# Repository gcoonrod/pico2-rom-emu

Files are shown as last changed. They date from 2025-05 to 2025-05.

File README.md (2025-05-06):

# Pico2-ROM-Emu

Pico2-ROM-Emu is a project designed to emulate 28 pin EEPROM (28C256 compatible) functionality using the Raspberry Pi Pico2 and a fast SRAM.

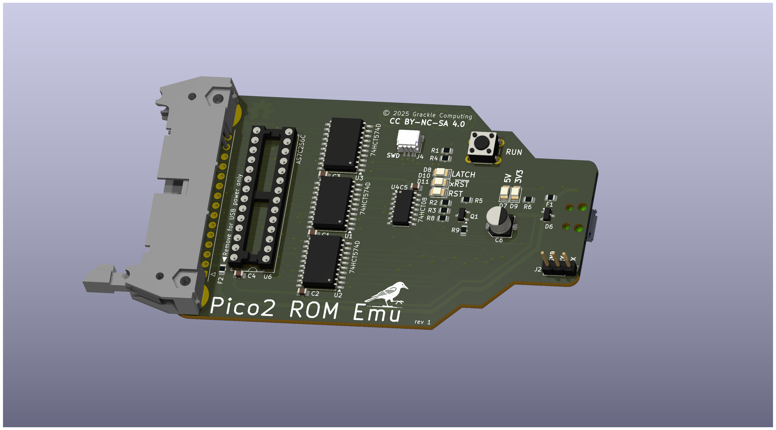
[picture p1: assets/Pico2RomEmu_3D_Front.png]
front render


## Theory of Operation
The theory of operation is relatively simple:

1. Assert active-low reset signal
2. Fill SRAM with ROM data using octal latches 
3. Hi-Z the latches and de-assert reset
4. SRAM is directly connected to DUT EEPROM socket via ribbon cable 

## Circuit Schematic
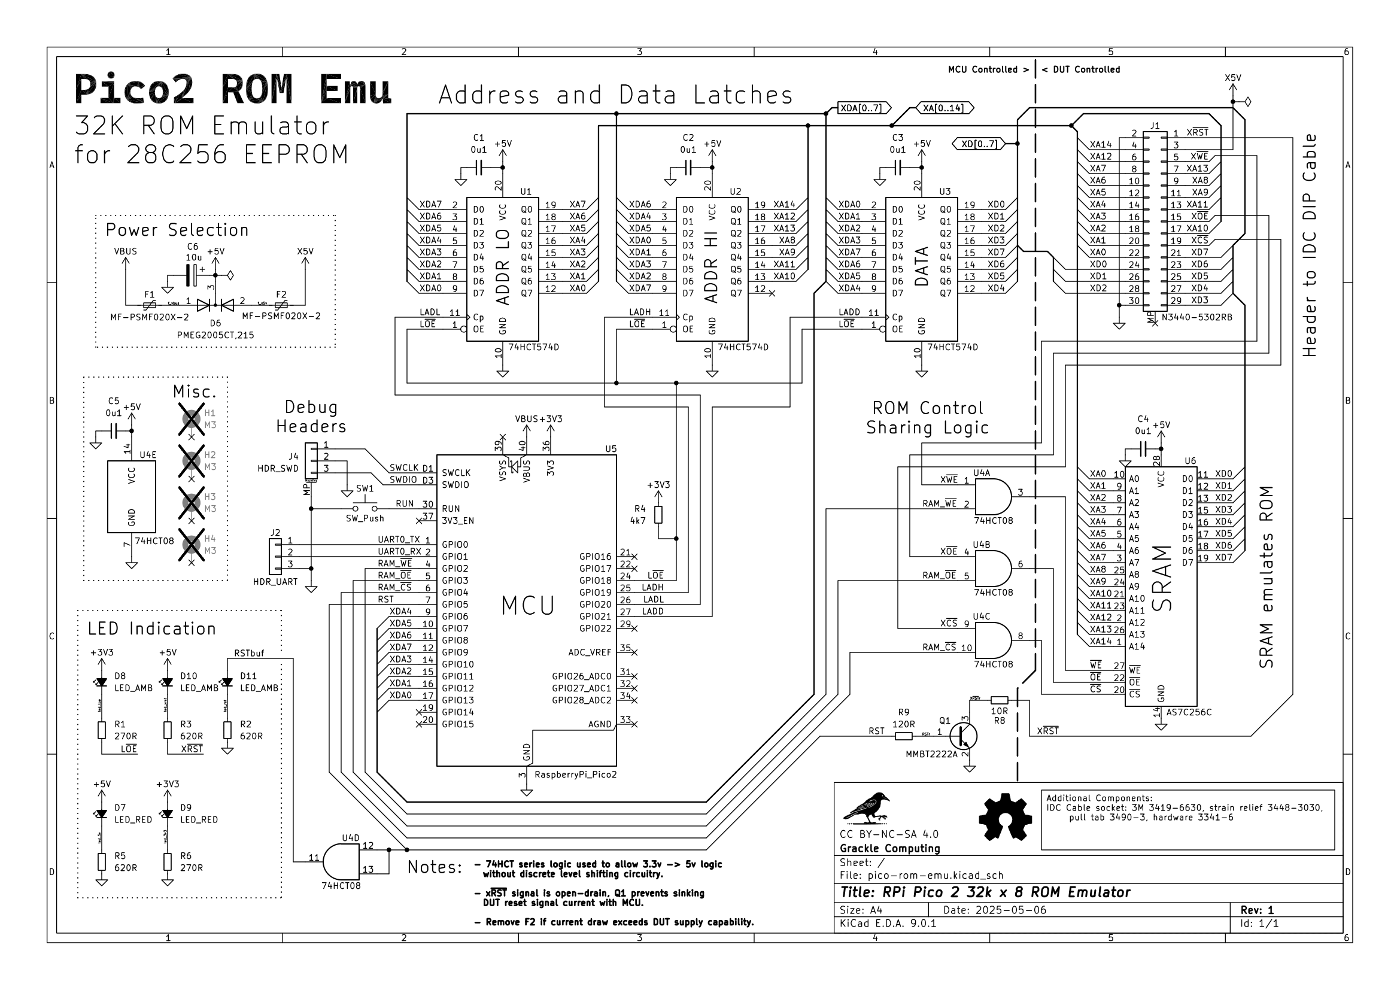
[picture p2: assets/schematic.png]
schematic diagram


## MicroPython Firmware (`pico-rom-emu-firmware`)
This sub-project contains the firmware written in MicroPython. It is responsible for:
- Copying provided ROM binary images to the embedded SRAM
- Accepting new ROM images over USB serial connection
- Controlling DUT reset signal

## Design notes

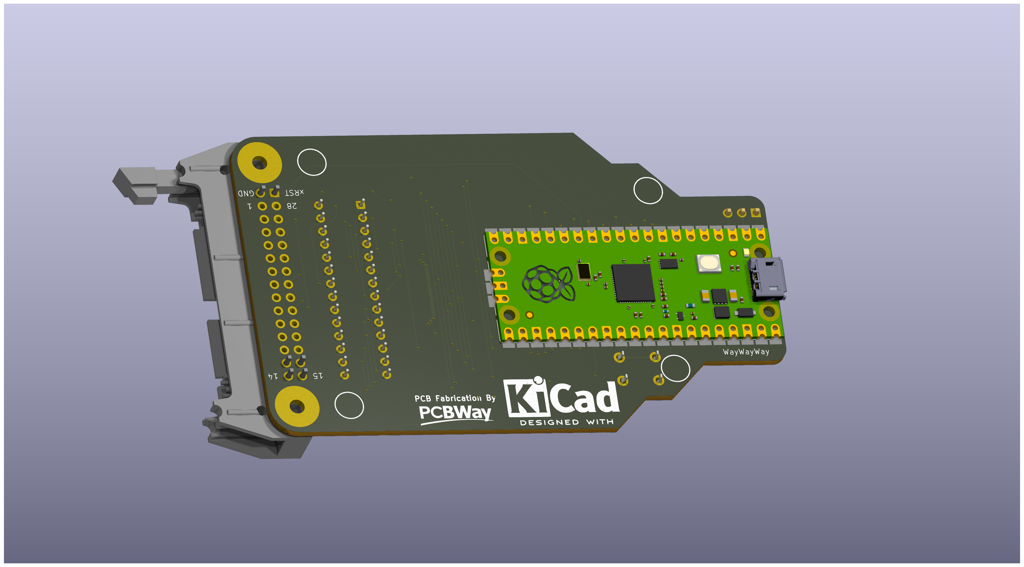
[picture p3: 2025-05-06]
assets/Pico2RomEmu_3D_Back.png

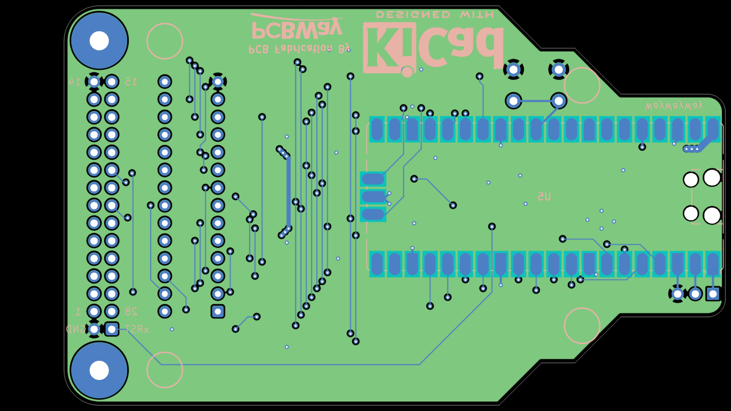
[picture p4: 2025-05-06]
assets/Pico2RomEmu_Back.png

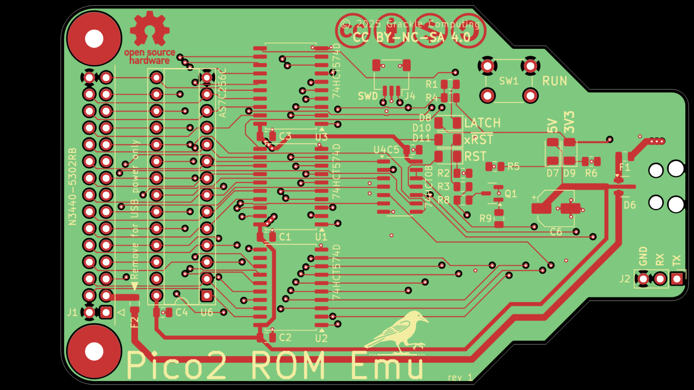
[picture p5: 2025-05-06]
assets/Pico2RomEmu_Front.png

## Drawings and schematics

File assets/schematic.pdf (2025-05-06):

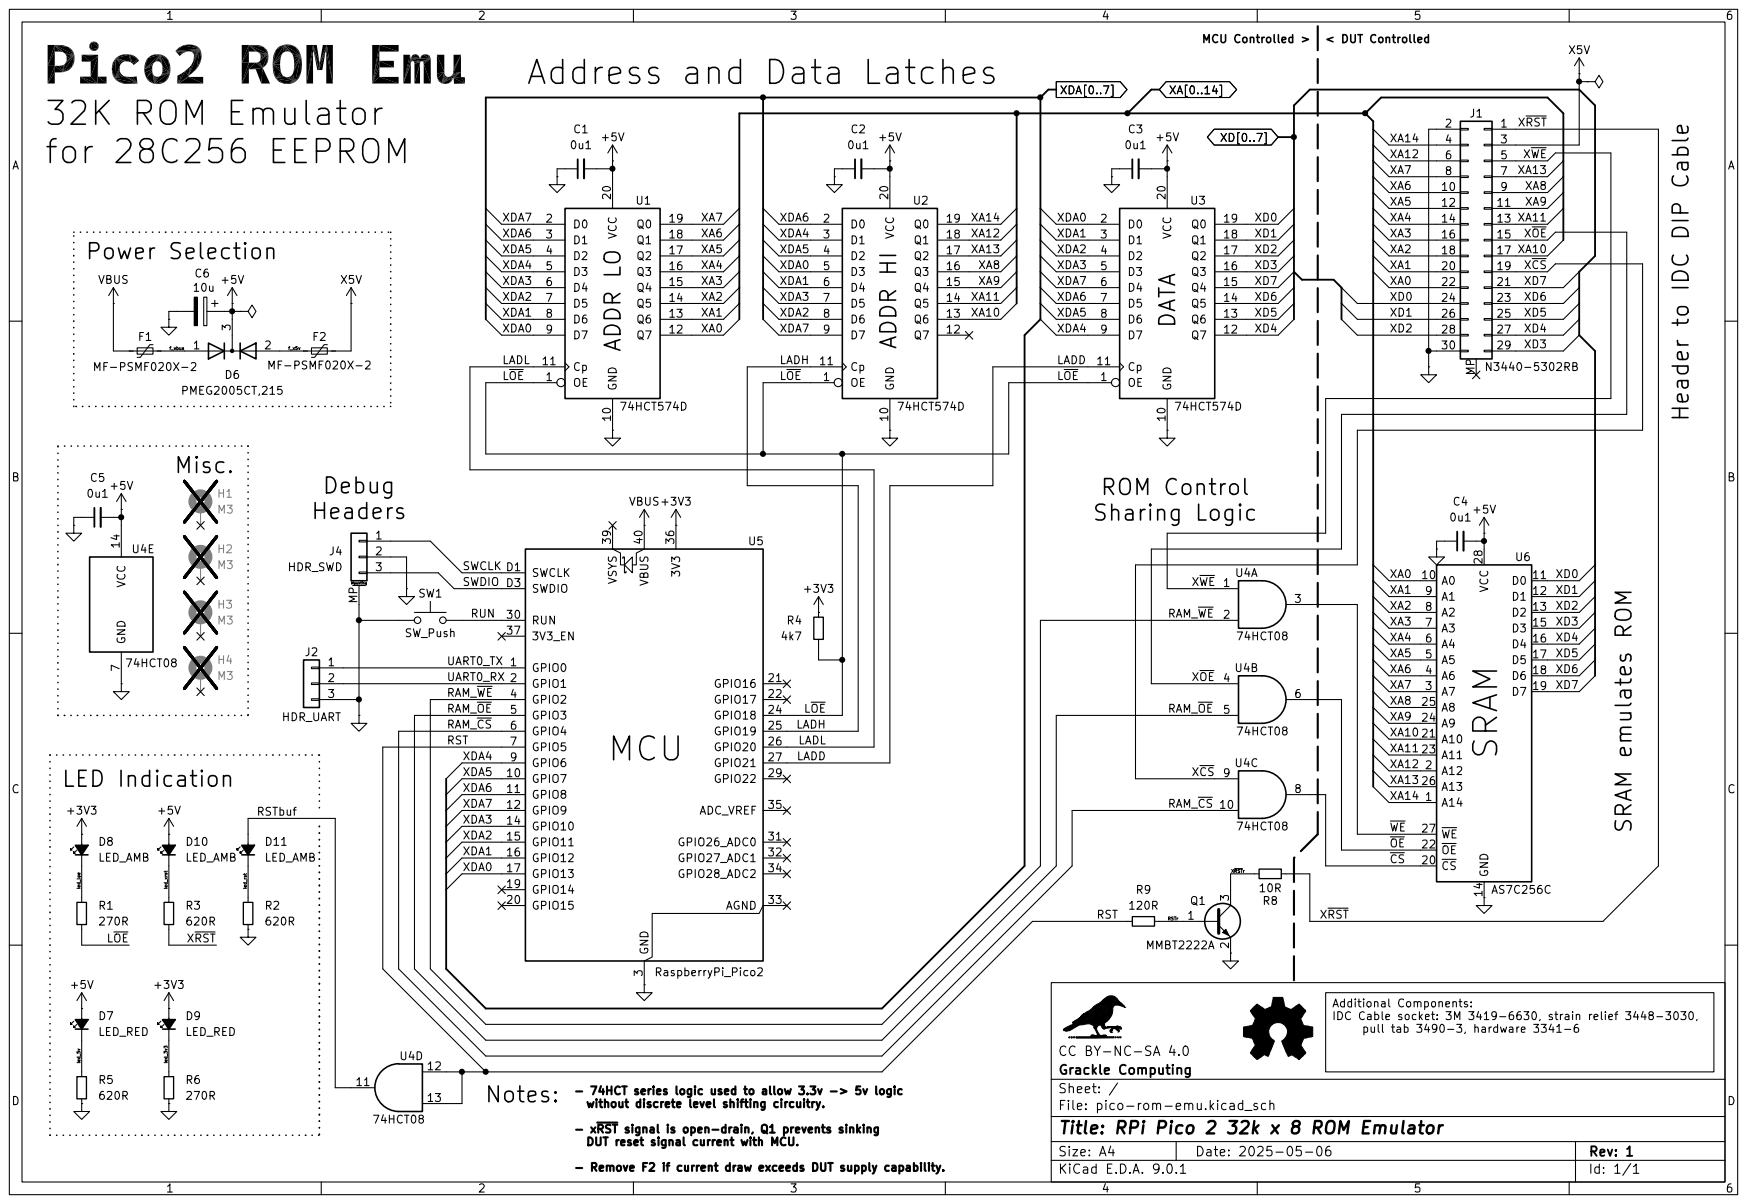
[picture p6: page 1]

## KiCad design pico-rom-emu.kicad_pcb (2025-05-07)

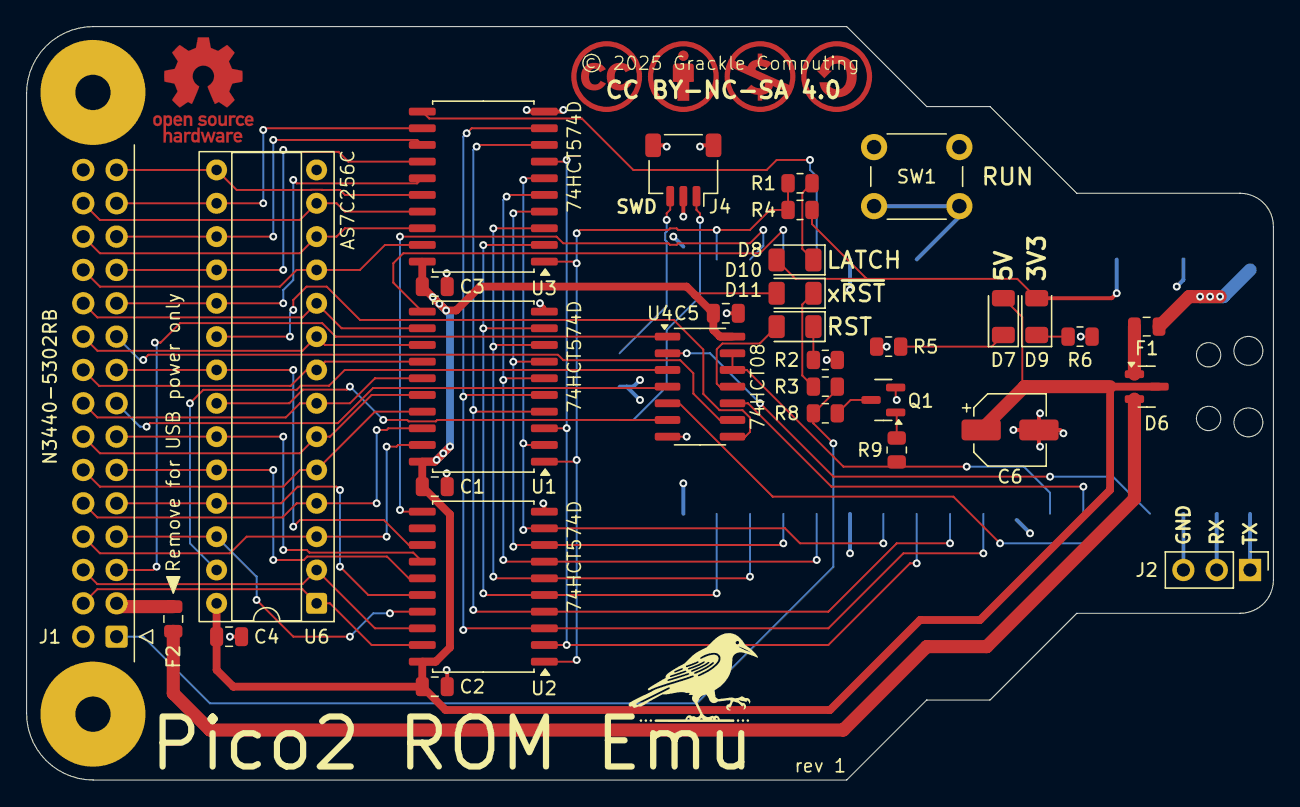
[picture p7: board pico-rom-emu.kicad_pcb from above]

Board: 4 copper layers, 95.0 x 57.4 mm, 34 parts (1 on the bottom side), 66 nets.

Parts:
C1, C2, C3, C4, C5: 0u1; C_0805_2012Metric
C6: 10u; CP_Elec_5x5.4
D6: PMEG2005CT,215; SOT-23
D7, D9: LED_RED; LED_1206_3216Metric
D8, D10, D11: LED_AMB; LED_1206_3216Metric
F1, F2: MF-PSMF020X-2; Fuse_0805_2012Metric
G1: LOGO; GrackleLogo12mm
J1: N3440-5302RB; IDC-Header_2x15-1MP_P2.54mm_Latch_Horizontal
J2: HDR_UART; PinHeader_1x03_P2.54mm_Vertical
J4: HDR_SWD; JST_SH_SM03B-SRSS-TB_1x03-1MP_P1.00mm_Horizontal
Q1: MMBT2222A; SOT-23
R1, R5, R9: 1k8; R_0805_2012Metric
R2, R3, R6: 680R; R_0805_2012Metric
R4: 3k3; R_0805_2012Metric
R8: 10R; R_0805_2012Metric
SW1: SW_Push; SW_PUSH_6mm
U1, U2, U3: 74HCT574D; SOIC-20W_7.5x12.8mm_P1.27mm
U4: 74HCT08; SOIC-14_3.9x8.7mm_P1.27mm
U5: RaspberryPi_Pico2; RaspberryPi_Pico_SMD_HandSolder
U6: AS7C256C; DIP-28_W7.62mm_Socket

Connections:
+3V3: D8.2 (A), D9.2 (A), R4.1, U5.36 (3V3)
+5V: C1.2, C2.2, C3.2, C4.2, C5.2, C6.1, D6.3 (K), D7.2 (A), D10.2 (A), U1.20 (VCC), U2.20 (VCC), U3.20 (VCC), U4.14 (VCC), U6.28 (VCC)
/LADD: U3.11 (Cp), U5.27 (GPIO21)
/LADH: U2.11 (Cp), U5.25 (GPIO19)
/LADL: U1.11 (Cp), U5.26 (GPIO20)
/L~OE: R1.2, R4.2, U1.1 (OE), U2.1 (OE), U3.1 (OE), U5.24 (GPIO18)
/RAM_~CS: U4.10, U5.6 (GPIO4)
/RAM_~OE: U4.5, U5.5 (GPIO3)
/RAM_~WE: U4.2, U5.4 (GPIO2)
/RST: R9.1, U4.12, U4.13, U5.7 (GPIO5)
/RSTbuf: D11.2 (A), U4.11
/RSTr: Q1.1 (B), R9.2
/RUN: SW1.1, U5.30 (RUN)
/SWCLK: J4.1, U5.D1 (SWCLK)
/SWDIO: J4.3, U5.D3 (SWDIO)
/UART0_RX: J2.2, U5.2 (GPIO1)
/UART0_TX: J2.1, U5.1 (GPIO0)
/X~CS: J1.19, U4.9
/X~OE: J1.15, U4.4
/X~RST: J1.1, R3.2, R8.2
/X~RSTr: Q1.3 (C), R8.1
/X~WE: J1.5, U4.1
/f_vbus: D6.1 (A), F1.2
/f_x5v: D6.2 (A), F2.1
/led_3v3: D9.1 (K), R6.1
/led_5v: D7.1 (K), R5.1
/led_loe: D8.1 (K), R1.1
/led_rst: D11.1 (K), R2.1
/led_xrst: D10.1 (K), R3.1
/~CS: U4.8, U6.20 (~CS)
/~OE: U4.6, U6.22 (~OE)
/~WE: U4.3, U6.27 (~WE)
GND: C1.1, C2.1, C3.1, C4.1, C5.1, C6.2, J1.2, J1.30, J2.3, J4.2, J4.MP (MountPin), Q1.2 (E), R2.2, R5.2, R6.2, SW1.2, U1.10 (GND), U2.10 (GND), U3.10 (GND), U4.7 (GND), U5.3 (GND), U5.8 (GND), U5.13 (GND), U5.18 (GND), U5.23 (GND), U5.28 (GND), U5.38 (GND), U5.D2 (GND), U6.14 (GND)
VBUS: F1.1, U5.40 (VBUS)
X5V: F2.2, J1.3
XA0: J1.22, U1.12 (Q7), U6.10 (A0)
XA1: J1.20, U1.13 (Q6), U6.9 (A1)
XA2: J1.18, U1.14 (Q5), U6.8 (A2)
XA3: J1.16, U1.15 (Q4), U6.7 (A3)
XA4: J1.14, U1.16 (Q3), U6.6 (A4)
XA5: J1.12, U1.17 (Q2), U6.5 (A5)
XA6: J1.10, U1.18 (Q1), U6.4 (A6)
XA7: J1.8, U1.19 (Q0), U6.3 (A7)
XA8: J1.9, U2.16 (Q3), U6.25 (A8)
XA9: J1.11, U2.15 (Q4), U6.24 (A9)
XA10: J1.17, U2.13 (Q6), U6.21 (A10)
XA11: J1.13, U2.14 (Q5), U6.23 (A11)
XA12: J1.6, U2.18 (Q1), U6.2 (A12)
XA13: J1.7, U2.17 (Q2), U6.26 (A13)
XA14: J1.4, U2.19 (Q0), U6.1 (A14)
XD0: J1.24, U3.19 (Q0), U6.11 (D0)
XD1: J1.26, U3.18 (Q1), U6.12 (D1)
XD2: J1.28, U3.17 (Q2), U6.13 (D2)
XD3: J1.29, U3.16 (Q3), U6.15 (D3)
XD4: J1.27, U3.12 (Q7), U6.16 (D4)
XD5: J1.25, U3.13 (Q6), U6.17 (D5)
XD6: J1.23, U3.14 (Q5), U6.18 (D6)
XD7: J1.21, U3.15 (Q4), U6.19 (D7)
XDA0: U1.9 (D7), U2.5 (D3), U3.2 (D0), U5.17 (GPIO13)
XDA1: U1.8 (D6), U2.6 (D4), U3.3 (D1), U5.16 (GPIO12)
XDA2: U1.7 (D5), U2.8 (D6), U3.4 (D2), U5.15 (GPIO11)
XDA3: U1.6 (D4), U2.7 (D5), U3.5 (D3), U5.14 (GPIO10)
XDA4: U1.5 (D3), U2.3 (D1), U3.9 (D7), U5.9 (GPIO6)
XDA5: U1.4 (D2), U2.4 (D2), U3.8 (D6), U5.10 (GPIO7)
XDA6: U1.3 (D1), U2.2 (D0), U3.7 (D5), U5.11 (GPIO8)
XDA7: U1.2 (D0), U2.9 (D7), U3.6 (D4), U5.12 (GPIO9)

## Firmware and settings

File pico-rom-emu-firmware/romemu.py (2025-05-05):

# pico-rom-emu-firmware (c) by Greg Coonrod
#
# pico-rom-emu-firmware is licensed under a
# Creative Commons Attribution-NonCommercial-ShareAlike 4.0 International License.
#
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
from machine import Pin, UART
from utime import sleep_us, ticks_ms, sleep_ms
from sys import print_exception, stdin, stdout
import select
import struct  # For packing/unpacking address

DEBUG = False

# RAM control pins for WEb, OEb, and CSb
pin_ram_web = Pin(7, Pin.OUT)
pin_ram_oeb = Pin(8, Pin.OUT)
pin_ram_csb = Pin(9, Pin.OUT)

# Latch control pins for LADL, LADH, and LADD
pin_ladl = Pin(10, Pin.OUT)
pin_ladh = Pin(11, Pin.OUT)
pin_ladd = Pin(12, Pin.OUT)

# Reset pin
pin_rstb = Pin(14, Pin.OUT)

# eXternal Data and Address pins (XDA)
pin_xda7 = Pin(15, Pin.OUT)
pin_xda6 = Pin(16, Pin.OUT)
pin_xda5 = Pin(17, Pin.OUT)
pin_xda4 = Pin(18, Pin.OUT)
pin_xda3 = Pin(19, Pin.OUT)
pin_xda2 = Pin(20, Pin.OUT)
pin_xda1 = Pin(21, Pin.OUT)
pin_xda0 = Pin(22, Pin.OUT)

# Latch Output Enable pin
pin_loeb = Pin(26, Pin.OUT)


# --- Pin Initialization ---
def init_pins():
    pin_ram_web.on()
    pin_ram_oeb.on()
    pin_ram_csb.on()
    pin_ladl.off()
    pin_ladh.off()
    pin_ladd.off()
    pin_rstb.on()  # Start with reset de-asserted (system running)
    write_xda(0)  # Set XDA pins to output low
    pin_loeb.on()  # Latch outputs disabled initially


# --- XDA Bus Control ---
def write_xda(data):
    pin_xda7.value((data >> 7) & 0x01)
    pin_xda6.value((data >> 6) & 0x01)
    pin_xda5.value((data >> 5) & 0x01)
    pin_xda4.value((data >> 4) & 0x01)
    pin_xda3.value((data >> 3) & 0x01)
    pin_xda2.value((data >> 2) & 0x01)
    pin_xda1.value((data >> 1) & 0x01)
    pin_xda0.value(data & 0x01)


# --- RAM Write Function ---
def write_ram(addr, data):
    address_high = (addr >> 8) & 0xFF
    address_low = addr & 0xFF

    # Write high address byte
    write_xda(address_high)
    pin_ladh.on()
    sleep_us(1)
    pin_ladh.off()

    # Write low address byte
    write_xda(address_low)
    pin_ladl.on()
    sleep_us(1)
    pin_ladl.off()

    # Write data byte
    write_xda(data)
    pin_ladd.on()
    sleep_us(1)
    pin_ladd.off()

    # Pulse WEb to write
    pin_ram_web.off()
    sleep_us(1)
    pin_ram_web.on()


# --- Serial ROM Upload Function ---
def receive_rom_serial():
    """
    Waits for serial upload command 'U'.
    Receives a 2-byte little-endian starting address.
    Receives ROM data byte-by-byte until host sends 'E'.
    Writes received data to RAM.
    """
    # Use USB CDC serial
    # Set up polling object for stdin
    poll_obj = select.poll()
    poll_obj.register(stdin, select.POLLIN)

    print("Ready for serial ROM upload. Send 'U' to start.")

    # Wait for Upload command 'U'
    start_cmd = None
    while start_cmd != b"U":
        # Check if data is available on stdin
        poll_results = poll_obj.poll(1)  # Timeout after 1ms
        if poll_results:
            start_cmd = stdin.buffer.read(1)
        sleep_ms(10)  # Small delay to prevent busy-waiting

    print("Start command received.")
    stdout.buffer.write(b"A")  # Send Acknowledge

    # Receive 2-byte starting address (little-endian)
    addr_bytes = stdin.buffer.read(2)
    if len(addr_bytes) < 2:
        print("Error: Did not receive address.")
        return 0, 0  # Indicate error

    start_addr = struct.unpack("<H", addr_bytes)[
        0
    ]  # '<H' is little-endian unsigned short
    print(f"Receiving ROM data starting at address: 0x{start_addr:04X}")

    addr = start_addr
    bytes_written = 0
    start_time = ticks_ms()

    # Assert reset during upload
    pin_rstb.off()
    sleep_us(100)

    # Select RAM and enable latch output
    pin_ram_csb.off()
    pin_loeb.off()

    try:
        while True:
            # Wait for a byte, but check for End command 'E'
            # Use polling with a short timeout to remain responsive
            poll_results = poll_obj.poll(1000)  # Wait up to 1 second for data
            if not poll_results:
                print("Warning: Timeout waiting for data.")
                # Consider breaking or adding more robust error handling
                continue  # Keep waiting for now

            byte = stdin.buffer.read(1)

            if not byte:  # Should not happen with poll, but good practice
                print("Error: Serial connection closed unexpectedly.")
                break

            if byte == b"E":  # Check for End command
                print("End command received.")
                stdout.buffer.write(b"K")  # Send Confirmation
                break

            # Write the received byte to RAM
            write_ram(addr, byte[0])
            addr += 1
            bytes_written += 1

            # Optional: Add progress indicator
            if DEBUG and (bytes_written % 256 == 0):
                print(f"Received {bytes_written} bytes...")

    except Exception as e:
        print("Error during serial reception:")
        print_exception(e)
        bytes_written = 0  # Indicate failure
    finally:
        # De-select RAM, disable latch output (important first!)
        pin_ram_csb.on()
        pin_loeb.on()
        # De-assert reset *after* disabling RAM/latches
        pin_rstb.on()
        sleep_us(100)  # Give time for reset to propagate

    end_time = ticks_ms()
    return bytes_written, start_time, end_time, start_addr


# --- Main Execution ---
def main():
    init_pins()
    print("Pico ROM Emulator Ready.")
    print("Send 'U' over serial to upload a ROM.")

    while True:
        # Wait for and perform serial upload
        bytes_written, start_time, end_time, start_addr = receive_rom_serial()

        if bytes_written > 0:
            elapsed_ms = end_time - start_time
            elapsed_s = elapsed_ms / 1000.0
            write_speed = bytes_written / elapsed_s if elapsed_s > 0 else 0
            print(
                f"\nSuccessfully wrote {bytes_written} bytes starting at 0x{start_addr:04X} to RAM."
            )
            print(f"Time taken: {elapsed_s:.2f} seconds")
            print(f"Average write speed: {write_speed:.2f} bytes/second")
            print("\nSystem reset released. Emulator running...")
            print("Send 'U' again to upload another ROM.")
        else:
            print("\nROM upload failed or was cancelled.")
            print("Send 'U' to try again.")

        # The loop continues, waiting for the next 'U' command


if __name__ == "__main__":
    main()

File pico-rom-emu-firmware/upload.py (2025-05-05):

# pico-rom-emu (c) by Greg Coonrod
# 
# pico-rom-emu is licensed under a
# Creative Commons Attribution-NonCommercial-ShareAlike 4.0 International License.
# 
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
import serial
import sys
import time
import struct # For packing address

def upload_rom(serial_port, baud_rate, file_path, start_address):
    """
    Uploads a ROM file (.bin) to the Pico ROM Emulator over serial.

    Args:
        serial_port (str): The serial port the Pico is connected to (e.g., 'COM3', '/dev/ttyACM0').
        baud_rate (int): The baud rate (should match Pico configuration, though typically ignored for USB CDC).
        file_path (str): Path to the .bin ROM file.
        start_address (int): The starting memory address (0x0000 to 0xFFFF).
    """
    try:
        print(f"Opening serial port {serial_port} at {baud_rate} baud...")
        ser = serial.Serial(serial_port, baud_rate, timeout=2)
        time.sleep(1) # Give the serial port time to initialize

        print(f"Attempting to upload '{file_path}' starting at address 0x{start_address:04X}...")

        # 1. Send Start command 'U'
        print("Sending start command 'U'...")
        ser.write(b'U')
        ser.flush()

        # 2. Wait for Acknowledge 'A'
        print("Waiting for acknowledge 'A'...")
        ack = ser.read(1)
        if ack != b'A':
            print(f"Error: Expected 'A' acknowledgement, but received: {ack}")
            ser.close()
            return False
        print("Acknowledge received.")

        # 3. Send 2-byte starting address (little-endian)
        addr_bytes = struct.pack('<H', start_address) # '<H' = little-endian unsigned short
        print(f"Sending start address: 0x{start_address:04X} ({addr_bytes.hex()})")
        ser.write(addr_bytes)
        ser.flush()

        # 4. Send ROM data
        print("Sending ROM data...")
        bytes_sent = 0
        try:
            with open(file_path, "rb") as f:
                while True:
                    chunk = f.read(1) # Read one byte at a time
                    if not chunk:
                        break # End of file
                    ser.write(chunk)
                    bytes_sent += 1
                    if bytes_sent % 256 == 0:
                         print(f"Sent {bytes_sent} bytes...", end='\r')

            print(f"\nFinished sending {bytes_sent} bytes.")

        except FileNotFoundError:
            print(f"Error: File not found at '{file_path}'")
            ser.close()
            return False
        except Exception as e:
            print(f"Error reading file: {e}")
            ser.close()
            return False

        # 5. Send End command 'E'
        print("Sending end command 'E'...")
        ser.write(b'E')
        ser.flush()

        # 6. Wait for Confirmation 'K'
        print("Waiting for confirmation 'K'...")
        confirm = ser.read(1)
        if confirm == b'K':
            print("Confirmation 'K' received. Upload successful!")
            ser.close()
            return True
        else:
            print(f"Error: Expected 'K' confirmation, but received: {confirm}")
            ser.close()
            return False

    except serial.SerialException as e:
        print(f"Serial Error: {e}")
        return False
    except Exception as e:
        print(f"An unexpected error occurred: {e}")
        return False

if __name__ == "__main__":
    if len(sys.argv) != 4:
        print("Usage: python upload_rom.py <serial_port> <rom_file.bin> <start_address_hex>")
        print("Example: python upload_rom.py COM3 my_rom.bin 8000")
        sys.exit(1)

    port = sys.argv[1]
    rom_file = sys.argv[2]
    try:
        address = int(sys.argv[3], 16) # Interpret address as hexadecimal
        if not (0x0000 <= address <= 0xFFFF):
            raise ValueError("Start address must be between 0x0000 and 0xFFFF")
    except ValueError as e:
        print(f"Error: Invalid start address '{sys.argv[3]}'. {e}")
        sys.exit(1)

    # --- Configuration ---
    BAUD = 115200 # Baud rate often doesn't matter for USB CDC, but set it anyway

    if upload_rom(port, BAUD, rom_file, address):
        print("Upload completed successfully.")
    else:
        print("Upload failed.")
        sys.exit(1)

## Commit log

2025-04-17 rev 1 kicad
    [pico-rom-emu.kicad_pcb, pico-rom-emu.kicad_sch]
2025-04-22 pre rev1 order
    [pico-rom-emu.kicad_pcb, pico-rom-emu.kicad_sch]
2025-05-06 rev 1 pre-production clean up
    [pico-rom-emu.kicad_pcb, pico-rom-emu.kicad_sch]
2025-05-06 remove old schematic
2025-05-07 minor changes for rev 1 spin at oshpark
    [pico-rom-emu.kicad_pcb]

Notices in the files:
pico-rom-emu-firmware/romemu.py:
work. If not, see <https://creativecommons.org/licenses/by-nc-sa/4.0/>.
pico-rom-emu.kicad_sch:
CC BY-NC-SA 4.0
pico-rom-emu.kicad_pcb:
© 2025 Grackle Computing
